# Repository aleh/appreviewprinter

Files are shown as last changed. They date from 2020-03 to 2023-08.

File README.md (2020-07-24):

# App Store Review Printer

Lua-only firmware for an autonomous App Store review printer based on NodeMCU and a common thermal printer part.

It sits on your desk checking App Store RSS feed for your iOS app and prints new reviews when they arrive.

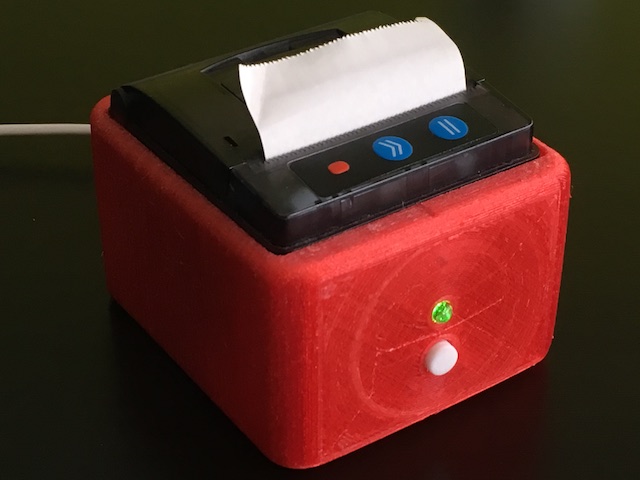
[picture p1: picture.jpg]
App Store Review Printer


## Configuration

The Makefile is tested with OS X only but should work on Linux. It assumes you have the amazing [nodemcu-uploader](https://github.com/kmpm/nodemcu-uploader) installed and that your NodeMCU device has its name matching `/dev/tty.wchusbserial*` pattern.

Rename `config-example.lua` to `config.lua` and adjust to suit your needs.

So far this has been tested with NodeMCU 1.5.4.1 (integer firmware). I've seen the newer one having problems with skipping of network data. 

Only regular modules are required in your firmware (HTTP and JSON parsing are done in Lua):

- bit
- file
- gpio
- net
- node
- struct
- tmr
- wifi

## Printer

Any stock thermal printer should work here, like the ones sold by Adafruit. And as always they have great docs here: https://cdn-learn.adafruit.com/downloads/pdf/mini-thermal-receipt-printer.pdf

Sparkfun also has related docs, though don't rely on all the commands available in every printer: 
https://www.sparkfun.com/datasheets/Components/General/Driver%20board.pdf

Nice intro on the typical ESC codes supported:
https://mike42.me/blog/what-is-escpos-and-how-do-i-use-it

Here is a link for a cheap 58mm one (turned out to be pretty narrow):
https://aliexpress.com/item/JP-QR203-58mm-Mini-Embedded-Receipt-Thermal-Printer-Compatible-with-EML203/32653084570.html

Name on the front: GOOJPRT

TTL connector wires (from left to right when looking at the PCB so the reset button in the top right corner):

        BLACK  - GND
        RED    - VCC
        YELLOW - RX (i.e. the data coming from the controller to the printer here).
        GREEN  - not sure, perhaps TX but could not confirm.
        BLUE   - sort of a BUSY signal: LOW when the printer is ready to accept incoming data; HIGH otherwise.

See `./doc/escpos.pdf` on some of the escape commands supported.

## Enclosure

The enclosure consists of two pieces that can be printed without support. (Put the front part, "Box Front.stl" and the button, "Button.stl", on their faces). Use 2.5 by 9 mm screws directly into plastic to attach the boards and the back cover. See `./enclosure` for STL and Fusion 360 sources. I used red PETG for the box (semi-transparent effect) and white PLA for the single button (for contrast) with 0.2 mm layers via 0.4 mm nozzle.

---

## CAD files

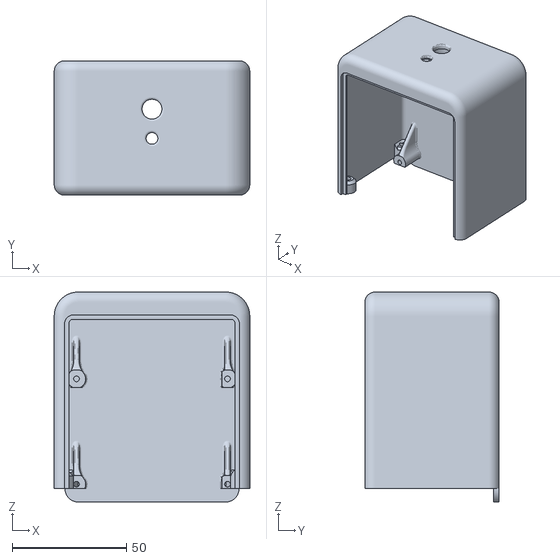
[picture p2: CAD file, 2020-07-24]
enclosure/Box Front.stl
85.5 x 58.7 x 91.8

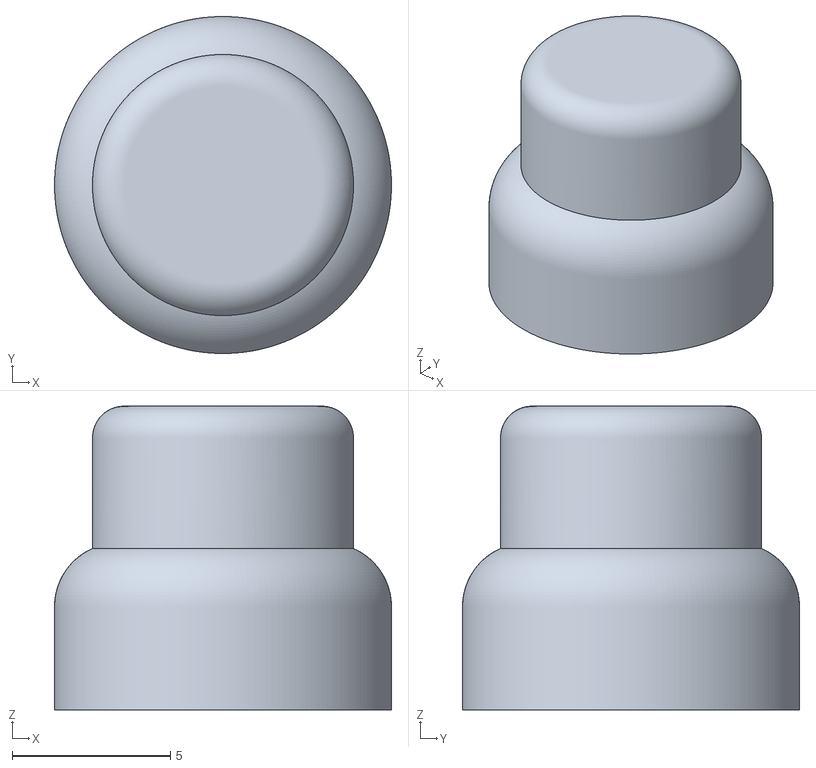
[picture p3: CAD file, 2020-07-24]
enclosure/Button.stl
10.7 x 10.6 x 9.60

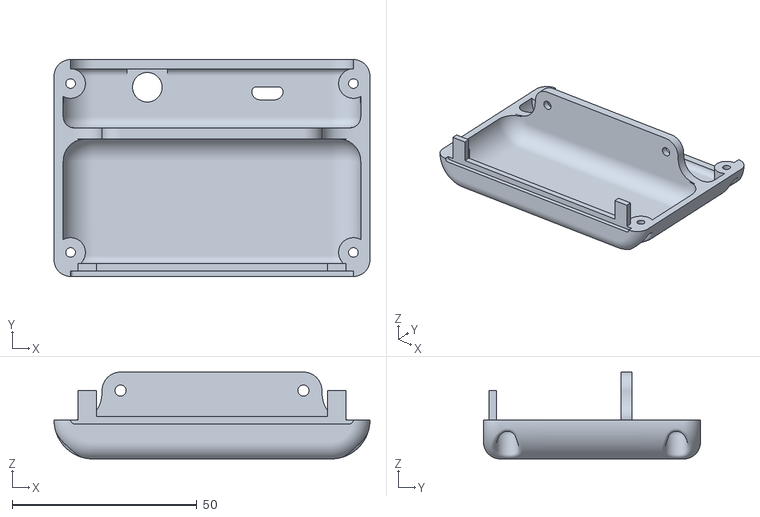
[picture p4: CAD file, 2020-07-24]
enclosure/Box Back.stl
85.5 x 58.7 x 23.5

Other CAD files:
enclosure/AppReviewPrinter.f3d

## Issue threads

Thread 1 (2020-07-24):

Could you please share your enclosure sources?

tpimh, 2020-07-24:
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
I really like your 3D printed enclosure for this project. Could you please share it's source or STL files?

aleh, 2020-07-24:
Hey! Thanks for the interest. Just committed both Fusion 360 sources and STL files.

tpimh, 2020-07-24:
Thank you very much!

Closed 2020-07-24.

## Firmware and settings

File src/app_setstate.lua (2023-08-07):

-- A "busy" LED is the one that lights up when our app_state is not idle.
local busy_led_pin = 2
local ready_led_pin = 3
local error_led_pin = 4

-- Not using the 'led' module as memory budget is almost zero.
--~ busy_led = _require('led')(busy_led_pin, 100, 800)
--~ busy_led.set_on(false)

--
-- The general state of the application.
--
app_state = 'idle'
app_substate = false

return function(new_state, new_substate)

    app_state = new_state
	app_substate = new_substate
    log("app_state: %s", app_state)
    
	if app_state ~= 'idle' then
        --~ busy_led.start_blinking()
		gpio.write(busy_led_pin, gpio.HIGH)
		gpio.write(ready_led_pin, gpio.LOW)
		gpio.write(error_led_pin, gpio.LOW)
	else
        --~ busy_led.stop_blinking()
		gpio.write(busy_led_pin, gpio.LOW)
		if app_substate ~= nil or app_substate then
			gpio.write(ready_led_pin, gpio.HIGH)
			gpio.write(error_led_pin, gpio.LOW)
		else
			gpio.write(ready_led_pin, gpio.LOW)
			gpio.write(error_led_pin, gpio.HIGH)
		end
	end

    log_heap()
end

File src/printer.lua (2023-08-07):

-- App Store Review Printer.
-- Copyright (C) 2018-2021, Aleh Dzenisiuk. All rights reserved.

-- GPIO pin which is used to detect whether the printer is busy or can accept our data.
local busy_pin = 5

-- GPIO pin which is used to send the data to the printer.
local tx_pin = 6

-- Max time in milliseconds the printer can be busy.
local printer_busy_timeout = 5 * 1000

-- Milliseconds to wait between the lines.
local line_interval = 0

local function log(message, ...)
    print(string.format("printer: " .. message, ...))
end     

-- Escapes non-ASCII characters in the given string. (%q of string.format() escapes only control characters)
local quoted = function(s)
    local result = ""
    for i = 1, s:len() do
        local b = s:byte(i)
        if 0x20 <= b and b <= 0x7e then
            result = result .. string.char(b)
        elseif b == 0x0a then
            result = result .. "\\n"
        else
            result = result .. string.format("\\x%02x", b)
        end
    end
    return "\"" .. result .. "\""
end

local _submit = function(lines, callback)

    log("Submitting %d lines...", #lines)

    -- Using a pullup, so it reads busy when not connected.
    gpio.mode(busy_pin, gpio.INPUT, gpio.PULLUP)
    
    local usart = _require('usart').new(tx_pin, 9600)

    local line_index = 1
    
    local retry_interval = 100
    local max_retry_counter = (printer_busy_timeout + retry_interval - 1) / retry_interval
    local retry_counter = 0
    
    local did_finish = function(error)
        usart:deinit()
        gpio.mode(busy_pin, gpio.INPUT, gpio.FLOAT)
        callback(error)
    end

    local submit_next_line
    submit_next_line = function()
        
        if line_index >= #lines then
            did_finish(nil)
        else
            if gpio.read(busy_pin) == gpio.LOW then
                
                retry_counter = 0

                local line = lines[line_index];
                usart:write(line .. "\n", function()
                    log("Sent line #%d, %d byte(s)", line_index, line:len() + 1)
                    line_index = line_index + 1
                    
                    if line_interval > 0 then
                        tmr.create():alarm(line_interval, tmr.ALARM_SINGLE, submit_next_line)
                    else
                        node.task.post(0, submit_next_line)
                    end
                end)
                
            else

                if retry_counter >= max_retry_counter then
                    
                    log("Still not available, giving up")
                    
                    if line_index == 0 then
                        did_finish("the printer is not available")
                    else
                        did_finish("the printer is stuck")
                    end
                    
                else
                    
                    if retry_counter == 0 then 
                        log("The printer is not available, will retry a couple of times just in case it's busy...")
                    end
                    
                    retry_counter = retry_counter + 1
                    
                    tmr.create():alarm(retry_interval, tmr.ALARM_SINGLE, function() 
                        node.task.post(0, submit_next_line)
                    end)
                end                
            end
        end
    end
    
    node.task.post(0, submit_next_line)
end

-- Prints a single partial review from the given DB which should be open for reading.
local _print_review = function(db, review, callback)
    
    log("Going to print review #%d", review.id)
    
    local r = db:full_review(review)
    if not r then
        callback(string.format("could not fetch the contents of the review #%d", review.id))
        return
    end
	
    -- Formatting in the next cycle to make sure we have plenty of time.
    node.task.post(0, function()

        local doc = _require("printer_doc")

        doc:empty_lines(1)

        -- Rating and title.
        local stars = function(n)
            local r = ""
            for i = 1, n do r = r .. "*" end
            for i = n + 1, 5 do r = r .. "·" end
            return r
        end
        doc:with_emphasis(function()
            doc:add_text(stars(r.rating))
            doc:add_text(" ")
            doc:add_text(r.title)
        end)
        doc:add_text("\n")
        
        -- Author.
        doc:with_small_font(function()
            doc:add_text(string.format("#%d, by ", r.id))
            doc:add_text(r.author)
        end)
        doc:empty_lines(1)
        
        -- The body can be too large to process in a single chunk, so splitting it.
        require("util").for_each_chunk(
            r.content, 
            64,
            function(chunk)
                -- TODO: switching to the small font and back can cause the current output position to accumulate error. Set small font beforehand instead.
                doc:with_small_font(function()
                    doc:add_text(chunk)
                end)
            end,
            function()
                
                doc:add_text("\n---\n")

                local lines = doc:finish()

                _submit(
                    lines,
                    function (error)
                        if error then
                            callback(string.format("could not print review #%d: %s", r.id, error))
                        else
                            log("Done printing #%d", review.id)
                            callback(nil)
                        end
                    end
                )
            end
        )
    end)
end
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

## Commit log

2018-02-09 Printing reviews WIP
2018-02-16 Make printing to a console work first
2018-02-25 Implement sending of data to printer
2018-03-03 Improve logging, print reviews with updated flag and use uhttp supporting chunked encoding
2018-03-13 When printing end the lines with LF instead of CRLF
2019-06-05 Support basic activity LED (though had to optimize memory to make it fit now)
2020-01-19 Basic schematics
    [appreviewprinter.kicad_pcb, appreviewprinter.sch]
2020-03-19 Add a picture of a prototype
2020-03-22 Support for LEDs button
2020-07-24 Add STL files and Fusion 360 sources of the enclosure
    [AppReviewPrinter.f3d, Box Back.stl, Box Front.stl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]
2020-07-24 Shorten some messages while helping with memory pressure
    [button.lua]
2020-07-24 fixup! Add STL files and Fusion 360 sources of the enclosure
2023-08-07 Split the app into overlays to handle mem pressure
